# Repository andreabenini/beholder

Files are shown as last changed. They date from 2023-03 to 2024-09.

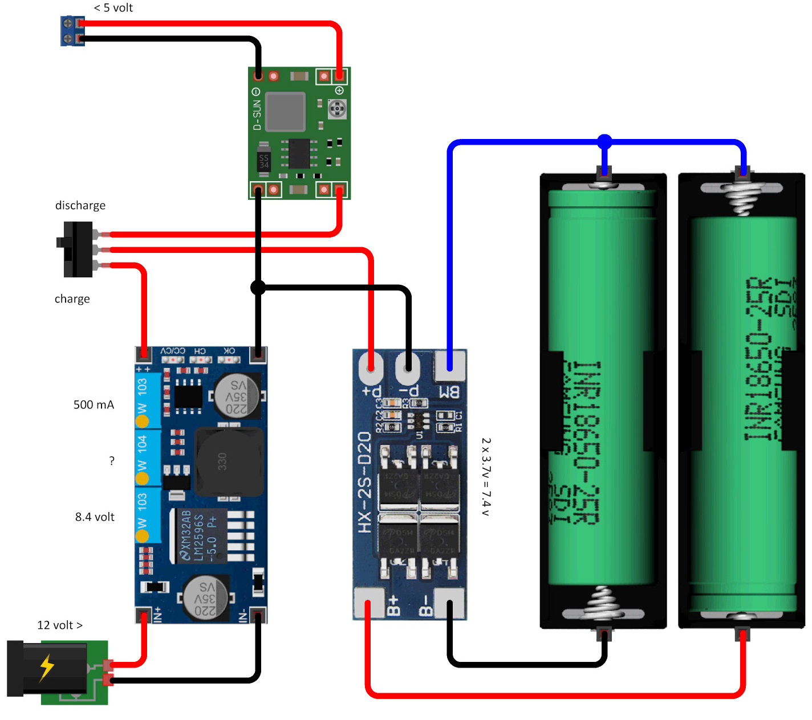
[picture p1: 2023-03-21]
hardware/bms+charger+batteries+PSU.jpg

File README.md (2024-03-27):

# Beholder
Small wheeled home patrol robot. It comes up in two shapes:
- **microguard**. Low profile and tiny bot  
    _Under active development, use it as a reference_
- **rollie**. Two wheeled, ball shaped, self balancing bot  
    _Mechanical assembly completed, on hold. Microguard has 
    now the priority_

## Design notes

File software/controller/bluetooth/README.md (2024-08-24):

| Supported Targets | ESP32 | ESP32-C2 | ESP32-C3 | ESP32-C6 | ESP32-H2 | ESP32-P4 | ESP32-S2 | ESP32-S3 |
| --- | ----- | --- | --- | --- | --- | --- | --- | --- |

# Bluetooth joypad controller sample software

## Folder contents

The project **sample_project** contains one source file in C language [main.c](main/main.c). The file is located in folder [main](main).

ESP-IDF projects are built using CMake. The project build configuration is contained in `CMakeLists.txt`
files that provide set of directives and instructions describing the project's source files and targets
(executable, library, or both). 

Below is short explanation of remaining files in the project folder.

```
├── CMakeLists.txt
├── main
│   ├── CMakeLists.txt
│   └── main.c
└── README.md                  This is the file you are currently reading
```
Additionally, the sample project contains Makefile and component.mk files, used for the legacy Make based build system. 
They are not used or needed when building with CMake and idf.py.

## sdkconfig
- `sdkconfig` file will be automatically generated with `idf.py set-target esp32` command and it's based on architecture feature
    related configuration `sdkconfig.defaults.*` files

## bluetooth
gamepad information
```txt
    BT : a0:5a:5e:11:ac:ff, COD: major: PERIPHERAL, minor: 2, service: 0x001, RSSI: -70, NAME: Wireless Controller
                            RSSI: -70, USAGE: GENERIC, COD: PERIPHERAL[GAMEPAD] srv 0x001, UUID16: 0x0000, NAME: Wireless Controller
```

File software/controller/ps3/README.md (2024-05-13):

# PS3 SixAxis DualShock BT Controller
This amazing electronic device is cheap and precise enough to be used as a primary 
input device for driving the robot when paired with a human.
I have decided to enable builtin bluetooth capabilities in order to support direct
connection with it, this directory contains utilities and documentation for a full
PS3 controller BT support.

## Sixpair utility
Compile and use it in order to attach your controller to the robot, address reported
in the PS3 controller should be the same of the bot firmware, for example:
```sh
./sixpair 1a:2b:3c:01:01:01
```
#### Compile
- This program uses dynamic usb libraries, usually they need to be installed and might
    have these names: `libusb-1_0-devel`, `libusb-compat-devel`.  
- `libusb-compat-devel` provides compatibility level with older linux bt stack somewhat
    mandatory to use it with the program
- Compile with: `gcc sixpair.c -lusb -o sixpair` or use `make.sh` provided utility

## Arduino demo
- Open Arduino IDE
- Menu File/Preferences, field: _"Additional Boards Manager URLs"_, add this board info:
    > https://dl.espressif.com/dl/package_esp32_index.json
- Press **OK** to confirm
- Menu _Tools/Boards/Board Manager_, search _"esp32"_ and select proper board: esp32-c3 or whatever
- Press **Install** button and then close the board manager with the **Close** button
- Menu _Tools/Manage Libraries_, search: _"ps3 controller host"_ and select the
    "Jeffrey van Pernis" library, press **Install** button and **Close** once done
- Open _"arduino_ps3/arduino_ps3.ino"_ sketch with Arduino IDE, verify, compile and upload as usual
    > #### arduino_ps3.ino
    > Arduino based test utility for dealing with ps3 controllers.
    > This sample uses the arduino IDE and provide a working demo for testing
    > controller pairing and basic events from keys and thumbsticks.

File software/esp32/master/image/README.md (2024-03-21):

## Partition table
Getting current partition table from the device
```sh
idf.py partition-table
# *******************************************************************************
## ESP-IDF Partition Table for this project
## Name,     Type,  SubType, Offset,   Size,  Flags
#  nvs,      data,  nvs,     0x9000,   16K,
#  otadata,  data,  ota,     0xd000,   8K,
#  phy_init, data,  phy,     0xf000,   4K,
#  factory,  app,   factory, 0x10000,  200K,
#  ota_0,    app,   ota_0,   0x50000,  1400K,
#  ota_1,    app,   ota_1,   0x1b0000, 1400K,
# *******************************************************************************
```

## Flashing device
```sh
# Default command applied from ESP-IDF Visual Studio Code plugin
/home/ben/.espressif/python_env/idf5.3_py3.11_env/bin/python
    /home/ben/esp/esp-idf/components/esptool_py/esptool/esptool.py
    -p /dev/ttyUSB0 -b 460800 --before default_reset --after hard_reset 
    --chip esp32 write_flash --flash_mode dio --flash_freq 40m
    --flash_size 4MB 
    0x1000 bootloader/bootloader.bin
    0x10000 server.bin
    0x8000 partition_table/partition-table.bin
    0xd000 ota_data_initial.bin

# Flashing a single partition, simplest command ever. Always check partition start address
python $IDF_PATH/components/esptool_py/esptool/esptool.py --chip esp32 --port /dev/ttyUSB0 write_flash 0x110000 ./build/server.bin
```

### Flashing software
```sh
export PORT=/dev/$(dmesg | grep -E 'pl2303.*ttyUSB' | tail -n 1 | awk '{print $NF}'); echo $PORT

# Partition OTA_0 only
python $IDF_PATH/components/esptool_py/esptool/esptool.py --port $PORT --baud 460800 --chip esp32 write_flash --flash_mode dio --flash_freq 40m --flash_size 4MB 0x50000 ./image/partition.ota0.bin

# Completely erase the MCU flash
python $IDF_PATH/components/esptool_py/esptool/esptool.py --port $PORT --baud 460800 --before default_reset --after hard_reset --chip esp32 erase_flash

# Init MCU with all my default values (dir: ~beholder/software/esp32/master)
export PORT=/dev/$(dmesg | grep -E 'pl2303.*ttyUSB' | tail -n 1 | awk '{print $NF}'); echo "Flashing on $PORT port"
python $IDF_PATH/components/esptool_py/esptool/esptool.py   \
    --port $PORT --baud 460800 --chip esp32 write_flash --flash_mode dio --flash_freq 40m --flash_size 4MB   \
    0x1000  ./image/bootloader.bin          \
    0x8000  ./image/partition-table.bin     \
    0xd000  ./image/ota_data_initial.bin    \
    0x10000 ./image/partition.factory.bin   \
    0x50000 ./build/server.bin

```

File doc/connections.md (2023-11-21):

# Peripherals and Connections

| Pro Mini | Type | Pins |
|---|---| ---: |
| Serial | Dedicated RX/TX | 2 |
| Motor 1 | PWM(1), Digital(2) | 3 |
| Motor 2 | PWM(1), Digital(2) | 3 |
| Servo Cam  | PWM(1) | 1 |
| Led | Digital I/O | 1 |
| DHT11 Temp | Analog ADC | 1 |
| Button | Digital | 1 |

| ESP32 | Type | Pins |
|---|---| ---: |
| Camera | Native | **ALL** |
| Serial | Dedicated RX/TX | 2 |

# External Links
- https://www.ebay.com/itm/384893528800

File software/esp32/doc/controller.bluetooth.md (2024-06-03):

# bluepad32 library

## Installation
**NOTE:** Execute all following steps in a IDF enabled shell, 
  see [Install](install.md) notes for it
```sh
# Clone repository
cd
cd esp
git clone https://github.com/bluekitchen/btstack
# git clone --recursive https://github.com/ricardoquesada/bluepad32.git
# # Apply provided patches
# cd bluepad32/external/btstack/
# git apply ../patches/*.patch
# Integrate it to ESP-IDF
cd port/esp32               # ~/esp/bluepad32/external/btstack/port/esp32
# - Double check $IDF_PATH environment variable, it must exists before proceeding
# - scripts always takes care about the ./components path and the entire ESP-IDF env.
#   It can also deal with updates too
./integrate_btstack.py
```

## Examples
- Located in bluepad32/examples/esp32
- `idf.py clean`
- `idf.py set-target esp32c3`
- `idf.py build`
- `idf.py -p /dev/ttyACM0 flash`
- `idf.py -p /dev/ttyACM0 monitor`

Configuration
- `idf.py -p /dev/ttyACM0 monitor`

&nbsp;<br>&nbsp;<br>&nbsp;<br>&nbsp;<br>

# Useful projects and links
- https://github.com/jvpernis/esp32-ps3 (not supporting latest ESP-IDF framework)
- https://github.com/openobjects/PS4-esp32 (a port of the above, somewhat workable but outdated too)
- https://www.google.com/search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
- https://github.com/ricardoquesada/bluepad32 (latest kid in town, based on btstack codebase)
- https://github.com/bluekitchen/btstack
- https://github.com/bluekitchen/btstack/tree/master/port/esp32
- https://bluekitchen-gmbh.com/btstack/#examples/examples/
- https://github.com/ricardoquesada/bluepad32/issues/65#issuecomment-1987046804
- https://github.com/ricardoquesada/bluepad32/issues?page=1&q=is%3Aissue
- https://bluepad32.readthedocs.io/en/stable/supported_gamepads/
- https://github.com/h2zero/esp-nimble-cpp

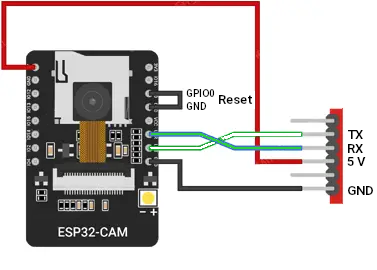
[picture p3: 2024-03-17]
software/esp32/doc/development.png

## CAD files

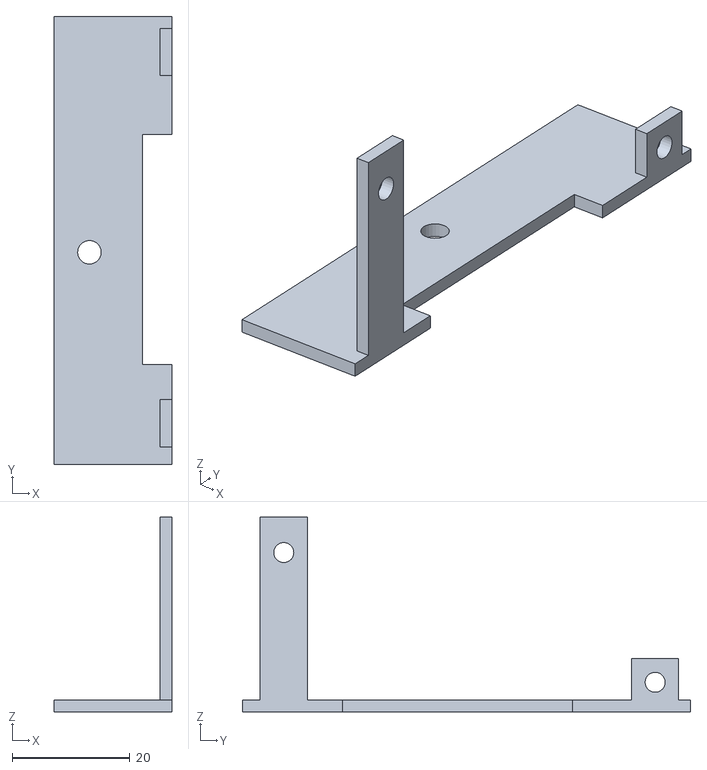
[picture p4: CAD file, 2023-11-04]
hardware/2.0/rollie2-ProMini Holder.stl
20.0 x 76.0 x 33.0

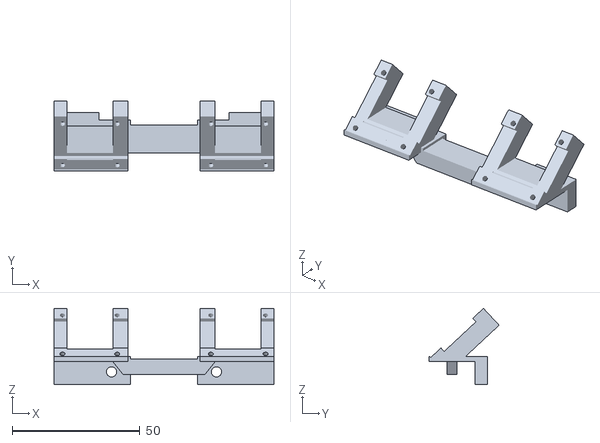
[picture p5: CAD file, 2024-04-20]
hardware/microguard.1.0/microguard-Display Holder.stl
86.0 x 27.5 x 29.8

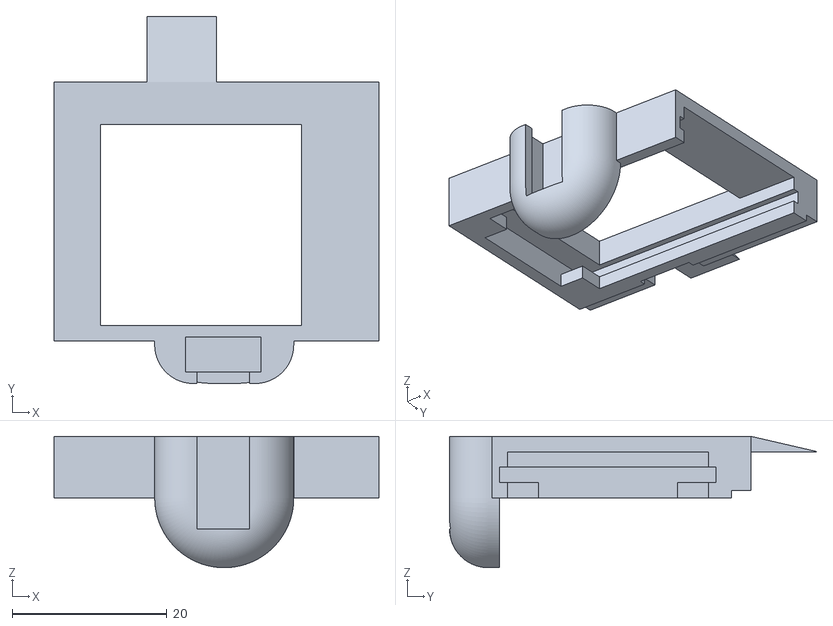
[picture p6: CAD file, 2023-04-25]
hardware/rollie-Camera Holder.stl
42.0 x 47.5 x 17.0

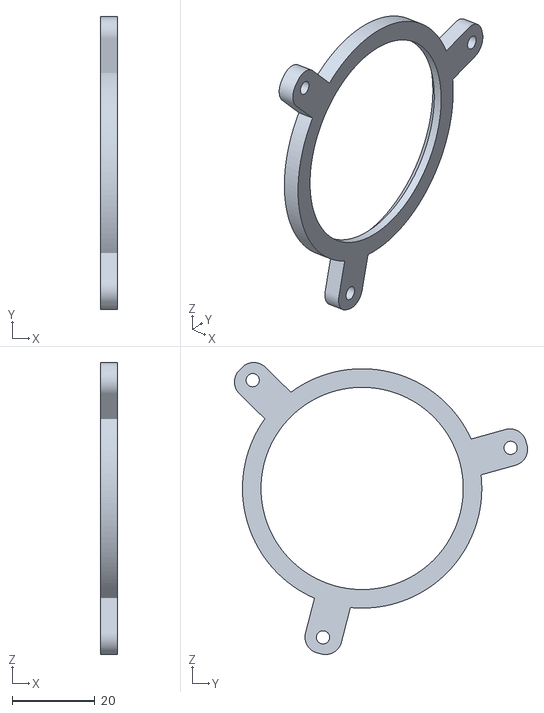
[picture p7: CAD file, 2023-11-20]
hardware/rollie.3.0/rollie3-Right Bearing Outer Cap Front.stl
4.00 x 71.0 x 70.8

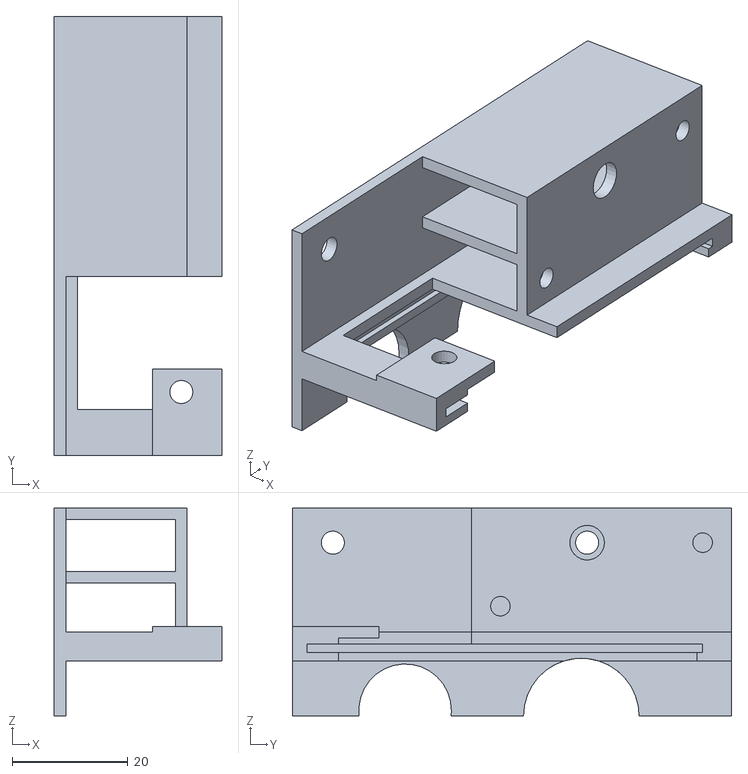
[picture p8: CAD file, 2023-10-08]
hardware/2.0/rollie2-Power Supply Board.stl
29.0 x 76.0 x 36.0

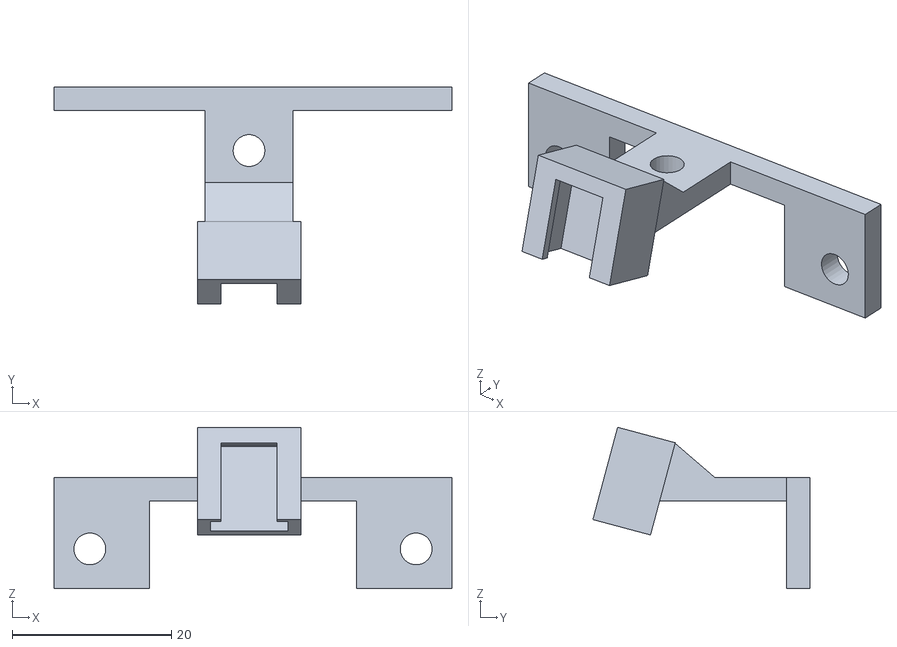
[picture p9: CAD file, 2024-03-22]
hardware/microguard.1.0/microguard-Camera holder.stl
50.0 x 27.3 x 20.3

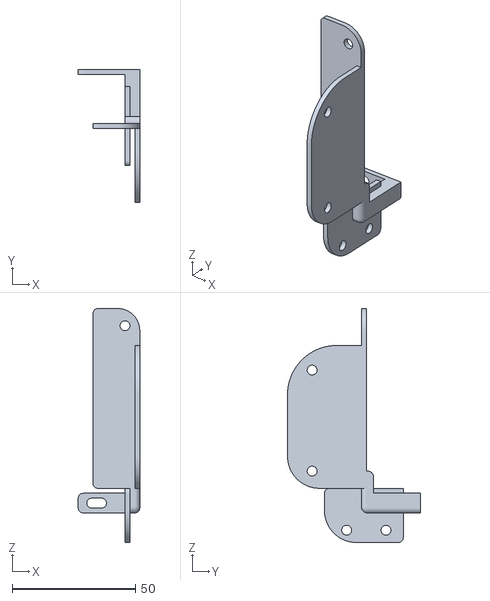
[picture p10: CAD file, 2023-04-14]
hardware/rollie-Arduino Mount.stl
25.0 x 54.0 x 95.0

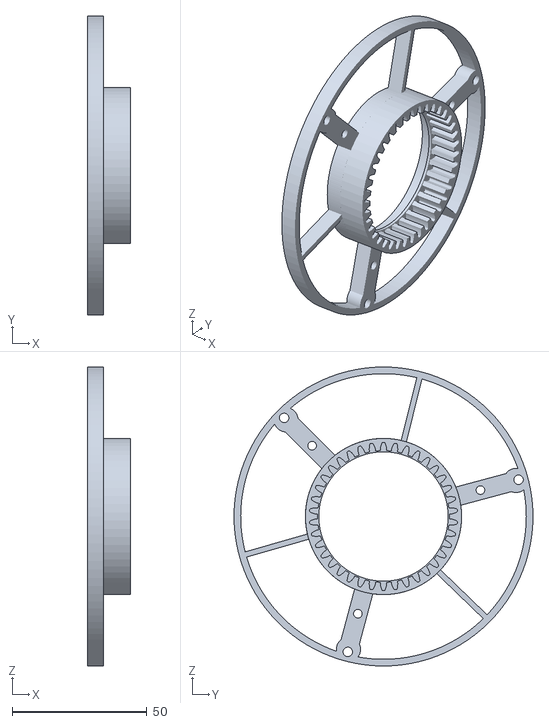
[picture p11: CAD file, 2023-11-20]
hardware/rollie.3.0/rollie3-Left Wheel Rim.stl
16.0 x 111.0 x 111.0

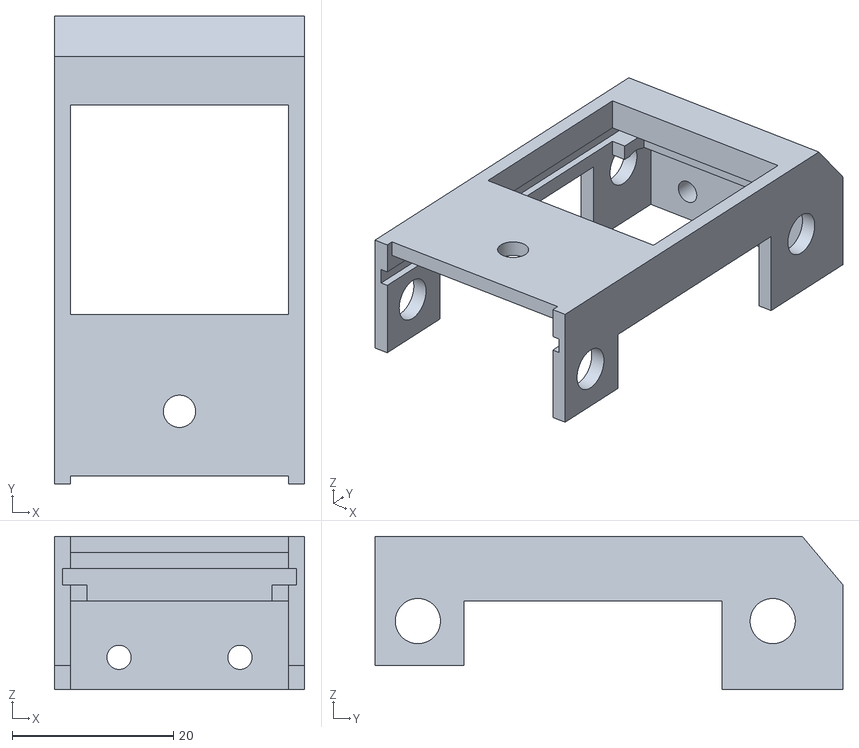
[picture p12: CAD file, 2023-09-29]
hardware/2.0/rollie2-ESP32 Holder.stl
31.0 x 58.0 x 19.0

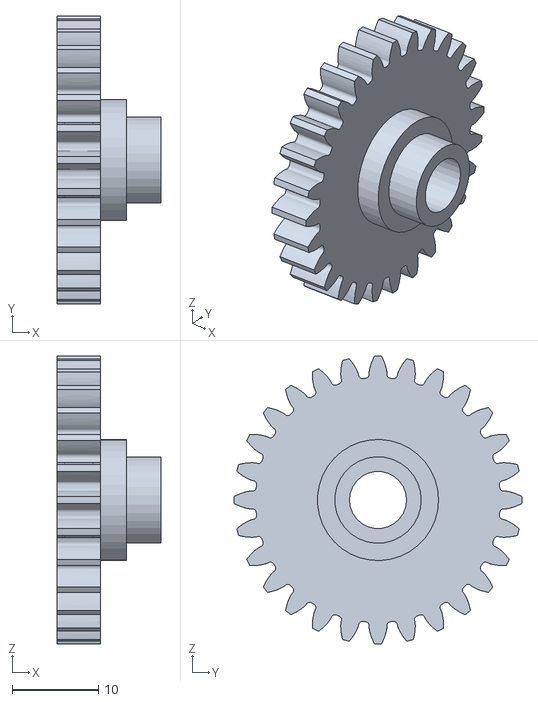
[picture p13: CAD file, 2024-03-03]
hardware/microguard.1.0/microguard-gear left.stl
12.0 x 33.3 x 33.3

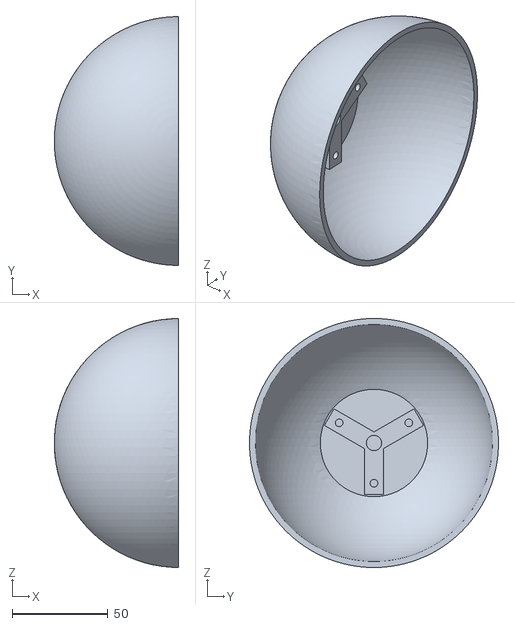
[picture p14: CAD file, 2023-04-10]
hardware/rollie-Wheel Left.stl
65.0 x 130.0 x 130.0

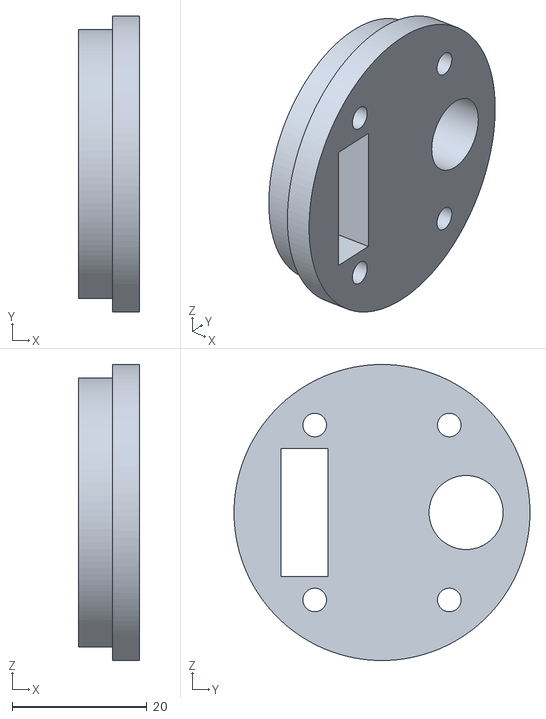
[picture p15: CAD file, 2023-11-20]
hardware/rollie.3.0/rollie3-Right Bearing Inner Front.stl
9.00 x 44.0 x 44.0

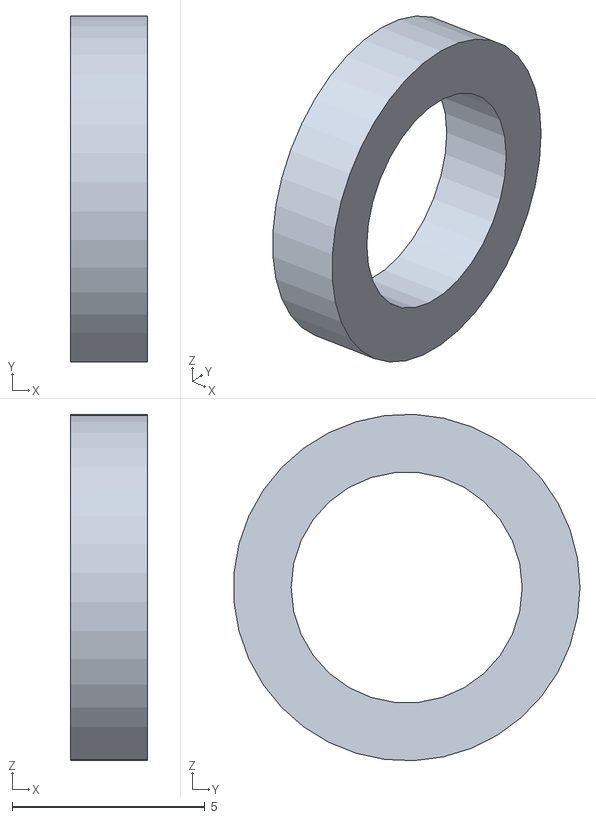
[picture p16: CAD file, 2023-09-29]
hardware/2.0/rollie2-Cylinder Spacer.stl
2.00 x 8.98 x 8.99

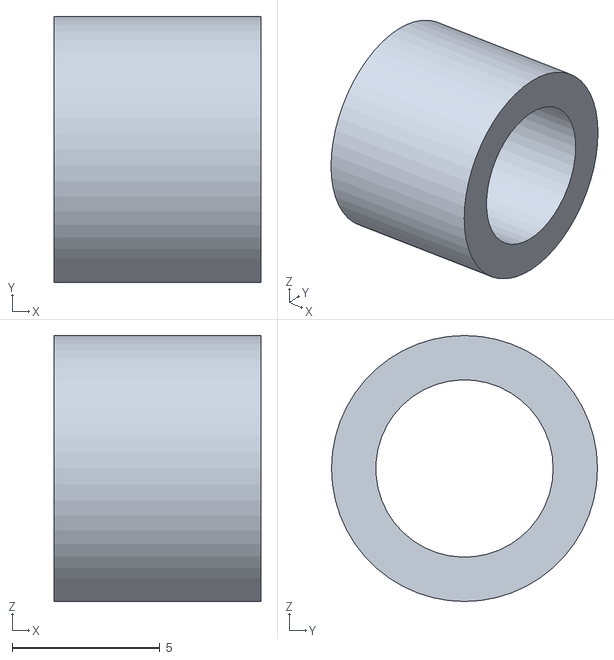
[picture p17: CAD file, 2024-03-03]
hardware/microguard.1.0/microguard-cylinder spacer2.stl
7.00 x 9.00 x 9.00

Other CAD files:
hardware/rollie-Base.stl
hardware/rollie.3.0/rollie3-Right Bearing InnerConnector.stl
hardware/2.0/rollie2-wheel Right Inner Back.stl
hardware/microguard.1.0/microguard-cylinder spacer1.stl
hardware/2.0/rollie2-Battery Holder Right.stl
hardware/2.0/rollie2-Battery Holder.stl
hardware/2.0/rollie2-Shoulder Left.stl
hardware/2.0/rollie2-Shoulder Right.stl
hardware/2.0/rollie2-servo Arm.stl
hardware/2.0/rollie2-wheel Left Cap Front.stl
hardware/2.0/rollie2-wheel Left Gear Pinion.stl
hardware/2.0/rollie2-wheel Left Inner Back.stl
hardware/2.0/rollie2-wheel Left Inner Front.stl
hardware/2.0/rollie2-wheel Left Wheel.stl
hardware/2.0/rollie2-wheel Right Cap Front.stl
hardware/2.0/rollie2-wheel Right Gear Pinion.stl
hardware/2.0/rollie2-wheel Right Inner Front.stl
hardware/2.0/rollie2-wheel Right Wheel.stl
hardware/3.0/rollie3-ESP32 Holder.stl
hardware/3.0/rollie3-Holder Spacer.stl
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

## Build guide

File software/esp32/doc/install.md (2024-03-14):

# Installation
## ESP-IDF
No visual studio code plugins are stricly required, you can use the whole environment from command line:
```sh
# Install ESP-IDF
mkdir $HOME/esp
cd esp
git clone --recursive https://github.com/espressif/esp-idf.git
cd esp-idf

# Install ESP32 Camera libraries
cd components
git clone https://github.com/espressif/esp32-camera
cd ..

# Add user to 'uucp' in /etc/group

# Install ESP-IDF
./install.sh all
```

### **Enter virtual environment**
```sh
# . ./export.sh
. $HOME/esp/esp-idf/export.sh
idf.py --help
# Examples in:  $HOME/esp/esp-idf/examples
```

### **Create and build a sample project**
```sh
cd ~/esp
cp -r $IDF_PATH/examples/get-started/hello_world .
cd hello_world
idf.py build
```

## Visual Studio Plugin: "Espressif IDF"
- Install the visual studio plugin from **Extensions**, it's called "Espressif IDF"
- From _Command Palette_ (Ctrl+Shift+P) select: **"ESP-IDF: Configure ESP-IDF extension"**
- To configure this extension there are two options: Express, Advanced. Select _"Express"_
- From configuration window set these values in fields:
  - Select download server: **Github**
  - Uncheck flag **"Show all ESP-IDF tags"**
  - Select ESP-IDF version: **Find ESP-IDF in your system**
  - Enter ESP-IDF directory (IDF_PATH): **/home/ben/esp/esp-idf**
  - Enter ESP-IDF Tools directory (IDF_TOOLS_PATH): **/home/ben/esp/esp-idf**
  - Select Python version: **/usr/bin/python**
- Close then window when all settings have been configured

# Project Management
## Project Setup
For every project, by default, IntelliSense is present, but the environment may not give
any indication if there is a problem. To fix that:
- Go to `.vscode` > `settings.json` and set the `C_Cpp.intelliSenseEngine` to `default`.  
  Previously it was set to `Tag Parser.`
- Now if there is an error in a C file, a red wavy line appears beneath that code

## New Project
To create a new ESP-IDF project just:
- Select: **"ESP-IDF: New Project"** from _"Command Palette" (Ctrl+Shift+P)_
- From 'New Project' form, first page:
  - Enter the project name
  - Enter the project directory
  - Choose ESP-IDF board, pick _'Custom Board'_ if unsure
  - if _Custom Board_ is selected the additional combo box: "Choose ESP-IDF Target"
    must be set to: "ESP32 module"
  - Select the dedicated serial port if applicable or let it unconfigured if unsure
  - Press "Choose Template" when finished
- From second page:
  - Set the combo box to "ESP-IDF", original value is: "Extension"
  - Select project skeleton: "`/ esp-idf / get-started / sample_project`"
  - Press button "Create project using template sample_project"
- A new project will be created
- Go to `.vscode` > `settings.json` and set the `C_Cpp.intelliSenseEngine` to `default`.  
  Previously it was set to `Tag Parser`. Now if there is an error in a C file, a red wavy
  line appears beneath that code
- Press button "ESP-IDF Build project" _(Ctrl+E, B)_ in the bottom bar to create the initial build

## Partitions information
From the shell in a properly set ESP-IDF terminal you can see current and active partition table
suitable for the device
```sh
idf.py partition-table
```

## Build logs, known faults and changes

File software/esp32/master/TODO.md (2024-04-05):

# Planned features
- Physical button on ATMega to reboot the ESP (or both devices)

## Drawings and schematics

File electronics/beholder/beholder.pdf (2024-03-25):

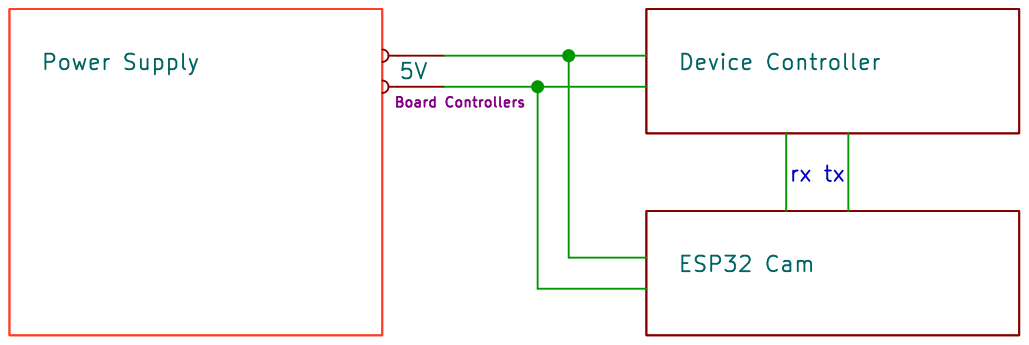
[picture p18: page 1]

File: beholder.kicad_sch Sheet: / Ben

Id: 1/4 Title: beholder Robot Schematics

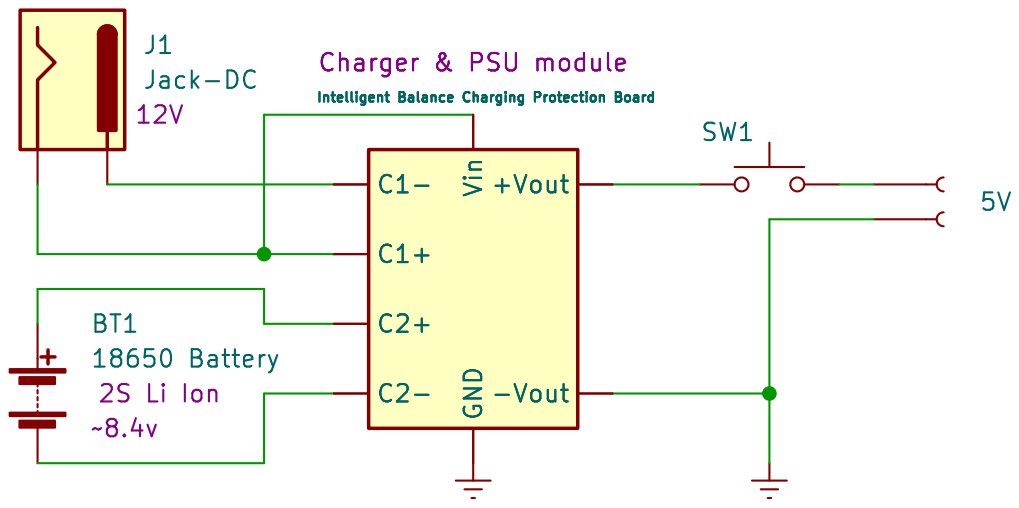
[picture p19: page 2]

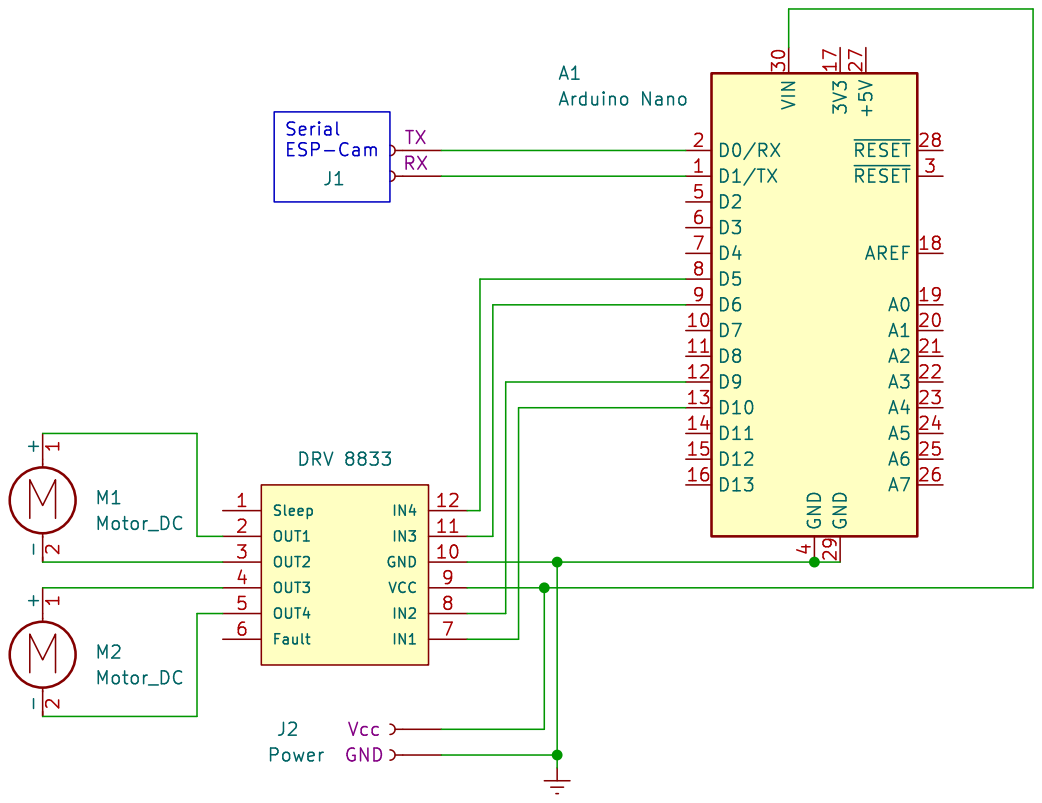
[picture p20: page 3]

TX Serial ESP-Cam

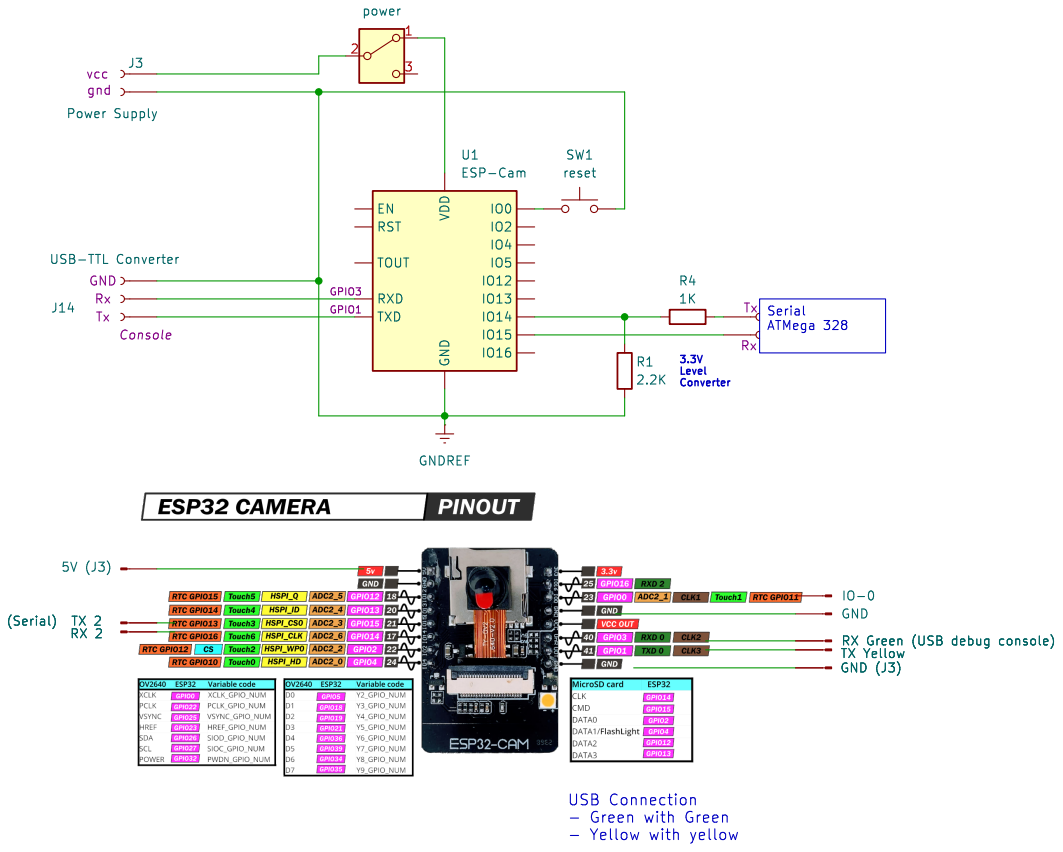
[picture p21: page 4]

IO-0 GND (J3) RX Green (USB debug console) SW1

1K J14 USB-TTL Converter Tx Rx GND

Id: 4/4 Title: File: espcam.kicad_sch Sheet: /ESP32 Cam/ GND

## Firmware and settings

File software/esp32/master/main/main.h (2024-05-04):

#ifndef MAIN__H
#define MAIN__H

#include "esp_task_wdt.h"

/**
 * Set project log level, Default is ESP_LOG_INFO. This define can disable logging all at once (for dealing with other serial devices for example)
 * Log level can also be changed with:
 *      - CONFIG_LOG_MAXIMUM_LEVEL setting in menuconfig
 *      - esp_log_level_set() in esp_log.h
 * Possible log values are:
 *      ESP_LOG_NONE
 *      ESP_LOG_ERROR
 *      ESP_LOG_WARN
 *      ESP_LOG_INFO        (default)
 *      ESP_LOG_DEBUG
 *      ESP_LOG_VERBOSE
 */
// #define LOG_LOCAL_LEVEL ESP_LOG_NONE


// Program configuration variables
#define VAR_LEN                     100

#define VAR_WIFI_SSID               "wifissid"
#define VAR_WIFI_PASSWORD           "wifipassword"
#define VAR_UPDATE_URL              "firmwareurl"
#define VAR_SECURITY_KEY            "secret"
// Bluetooth variables
#define VAR_BT_ADDRESS              "bluetooth"
// Camera variables
#define VAR_CAMERA_RESOLUTION       "cam_resolution"
#define VAR_CAMERA_QUALITY          "cam_quality"

#include "secret.h"
// Inside secret.h there are just these two definitions, feel free to create
// your secret.h file and keep them separated or uncomment those two lines below
// #define WIFI_SSID                   "yourSSID"
// #define WIFI_PASSWORD               "SecretWIFIPassword"
// [Default values] Wireless configuration
#define WIFI_MAX_RETRIES            5
#define WIFI_RETRY_TIMEOUT          1500        // ms
// [Default values] Bluetooth configuration
#define DEFAULT_BT_MAC_ADDRESS      "1a:2b:3c:01:01:01"
// [Default values] Firmware updates
#define DEFAULT_FIRMWARE_URL        "http://192.168.0.16:8000/firmware"
#define DEFAULT_SECURITY_KEY        "42"
// [Default values] camera settings
#define DEFAULT_CAMERA_RESOLUTION   "8"         // (sensor.h) typedef enum framesize_t
#define DEFAULT_CAMERA_QUALITY      "30"


// Camera configuration
// Program configuration
#define TAG_APP                     "Rollie"
// #define BOOTLOADER_ONLY


// User defined functions
// #define PROGRAM_HALT                esp_task_wdt_delete(NULL); while (1){vTaskDelay(portMAX_DELAY);}
#define PROGRAM_HALT                while (1){vTaskDelay(portMAX_DELAY);}

#endif

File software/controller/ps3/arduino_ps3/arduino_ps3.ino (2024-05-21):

#include <Ps3Controller.h>
/*
 *  Configuration Setup
 *      - ESP32-CAM
 *          Board: AI Thinker ESP32-CAM
 *          Library Manager:
 *              - Install: "ps3 controller host"
 */
//#define CONTROLLER_MAC  "1a:2b:3c:01:01:01"       // This will always work (it's not an unicast address)
#define CONTROLLER_MAC  "70:04:1d:93:89:a6"       // Device specific, set yours here

int player = 0;
int battery = 0;

void notify() {
    //--- Digital cross/square/triangle/circle button events ---
    if (Ps3.event.button_down.cross)
        Serial.println("Started pressing the cross button");
    if (Ps3.event.button_up.cross)
        Serial.println("Released the cross button");

    if (Ps3.event.button_down.square)
        Serial.println("Started pressing the square button");
    if (Ps3.event.button_up.square)
        Serial.println("Released the square button");

    if (Ps3.event.button_down.triangle)
        Serial.println("Started pressing the triangle button");
    if (Ps3.event.button_up.triangle)
        Serial.println("Released the triangle button");

    if (Ps3.event.button_down.circle)
        Serial.println("Started pressing the circle button");
    if (Ps3.event.button_up.circle)
        Serial.println("Released the circle button");

    //--------------- Digital D-pad button events --------------
    if (Ps3.event.button_down.up)
        Serial.println("Started pressing the up button");
    if (Ps3.event.button_up.up)
        Serial.println("Released the up button");

    if (Ps3.event.button_down.right)
        Serial.println("Started pressing the right button");
    if (Ps3.event.button_up.right)
        Serial.println("Released the right button");

    if (Ps3.event.button_down.down)
        Serial.println("Started pressing the down button");
    if (Ps3.event.button_up.down)
        Serial.println("Released the down button");

    if (Ps3.event.button_down.left)
        Serial.println("Started pressing the left button");
    if (Ps3.event.button_up.left)
        Serial.println("Released the left button");

    //------------- Digital shoulder button events -------------
    if (Ps3.event.button_down.l1)
        Serial.println("Started pressing the left shoulder button");
    if (Ps3.event.button_up.l1)
        Serial.println("Released the left shoulder button");

    if (Ps3.event.button_down.r1)
        Serial.println("Started pressing the right shoulder button");
    if (Ps3.event.button_up.r1)
        Serial.println("Released the right shoulder button");

    //-------------- Digital trigger button events -------------
    if (Ps3.event.button_down.l2)
        Serial.println("Started pressing the left trigger button");
    if (Ps3.event.button_up.l2)
        Serial.println("Released the left trigger button");

    if (Ps3.event.button_down.r2)
        Serial.println("Started pressing the right trigger button");
    if (Ps3.event.button_up.r2)
        Serial.println("Released the right trigger button");

    //--------------- Digital stick button events --------------
    if (Ps3.event.button_down.l3)
        Serial.println("Started pressing the left stick button");
    if (Ps3.event.button_up.l3)
        Serial.println("Released the left stick button");

    if (Ps3.event.button_down.r3)
        Serial.println("Started pressing the right stick button");
    if (Ps3.event.button_up.r3)
        Serial.println("Released the right stick button");

    //---------- Digital select/start/ps button events ---------
    if (Ps3.event.button_down.select)
        Serial.println("Started pressing the select button");
    if (Ps3.event.button_up.select)
        Serial.println("Released the select button");

    if (Ps3.event.button_down.start)
        Serial.println("Started pressing the start button");
    if (Ps3.event.button_up.start)
        Serial.println("Released the start button");

    if (Ps3.event.button_down.ps)
        Serial.println("Started pressing the Playstation button");
    if (Ps3.event.button_up.ps)
        Serial.println("Released the Playstation button");


    //---------------- Analog stick value events ---------------
   if (abs(Ps3.event.analog_changed.stick.lx) + abs(Ps3.event.analog_changed.stick.ly) > 2) {
       Serial.print("Moved the left stick:");
       Serial.print(" x="); Serial.print(Ps3.data.analog.stick.lx, DEC);
       Serial.print(" y="); Serial.print(Ps3.data.analog.stick.ly, DEC);
       Serial.println();
    }

   if (abs(Ps3.event.analog_changed.stick.rx) + abs(Ps3.event.analog_changed.stick.ry) > 2) {
       Serial.print("Moved the right stick:");
       Serial.print(" x="); Serial.print(Ps3.data.analog.stick.rx, DEC);
       Serial.print(" y="); Serial.print(Ps3.data.analog.stick.ry, DEC);
       Serial.println();
   }

   //--------------- Analog D-pad button events ----------------
   if (abs(Ps3.event.analog_changed.button.up)) {
       Serial.print("Pressing the up button: ");
       Serial.println(Ps3.data.analog.button.up, DEC);
   }

   if (abs(Ps3.event.analog_changed.button.right)) {
       Serial.print("Pressing the right button: ");
       Serial.println(Ps3.data.analog.button.right, DEC);
   }

   if (abs(Ps3.event.analog_changed.button.down)) {
       Serial.print("Pressing the down button: ");
       Serial.println(Ps3.data.analog.button.down, DEC);
   }

   if (abs(Ps3.event.analog_changed.button.left)) {
       Serial.print("Pressing the left button: ");
       Serial.println(Ps3.data.analog.button.left, DEC);
   }

   //---------- Analog shoulder/trigger button events ----------
   if (abs(Ps3.event.analog_changed.button.l1)) {
       Serial.print("Pressing the left shoulder button: ");
       Serial.println(Ps3.data.analog.button.l1, DEC);
   }

   if (abs(Ps3.event.analog_changed.button.r1)) {
       Serial.print("Pressing the right shoulder button: ");
       Serial.println(Ps3.data.analog.button.r1, DEC);
   }

   if (abs(Ps3.event.analog_changed.button.l2)) {
       Serial.print("Pressing the left trigger button: ");
       Serial.println(Ps3.data.analog.button.l2, DEC);
   }

   if (abs(Ps3.event.analog_changed.button.r2)) {
       Serial.print("Pressing the right trigger button: ");
       Serial.println(Ps3.data.analog.button.r2, DEC);
   }

   //---- Analog cross/square/triangle/circle button events ----
   if (abs(Ps3.event.analog_changed.button.triangle)) {
       Serial.print("Pressing the triangle button: ");
       Serial.println(Ps3.data.analog.button.triangle, DEC);
   }

   if (abs(Ps3.event.analog_changed.button.circle)) {
       Serial.print("Pressing the circle button: ");
       Serial.println(Ps3.data.analog.button.circle, DEC);
   }

   if (abs(Ps3.event.analog_changed.button.cross)) {
       Serial.print("Pressing the cross button: ");
       Serial.println(Ps3.data.analog.button.cross, DEC);
   }

   if (abs(Ps3.event.analog_changed.button.square)) {
       Serial.print("Pressing the square button: ");
       Serial.println(Ps3.data.analog.button.square, DEC);
   }

   //---------------------- Battery events ---------------------
    if (battery != Ps3.data.status.battery) {
        battery = Ps3.data.status.battery;
        Serial.print("The controller battery is ");
        if (battery == ps3_status_battery_charging)         Serial.println("charging");
        else if (battery == ps3_status_battery_full)        Serial.println("FULL");
        else if (battery == ps3_status_battery_high)        Serial.println("HIGH");
        else if (battery == ps3_status_battery_low)         Serial.println("LOW");
        else if (battery == ps3_status_battery_dying)       Serial.println("DYING");
        else if (battery == ps3_status_battery_shutdown)    Serial.println("SHUTDOWN");
        else Serial.println("UNDEFINED");
    }
} /**/

void onConnect() {
    Serial.println("Connected.");
} /**/

void setup() {
    Serial.begin(115200);
    Serial.println("setup() Begin");
    Ps3.attach(notify);
    Ps3.attachOnConnect(onConnect);
    Ps3.begin(CONTROLLER_MAC);             // Device specific, set yours here
    Serial.println("setup() Ready");
} /**/

void loop() {
    if (!Ps3.isConnected()) {
        return;
    }
    //-------------------- Player LEDs -------------------
    Serial.print("Setting LEDs to player "); Serial.println(player, DEC);
    Ps3.setPlayer(player);
    player += 1;
    if (player > 10) player = 0;

    //------ Digital cross/square/triangle/circle buttons ------
    if (Ps3.data.button.cross && Ps3.data.button.down )
        Serial.println("Pressing both the down and cross buttons");
    if (Ps3.data.button.square && Ps3.data.button.left )
        Serial.println("Pressing both the square and left buttons");
    if (Ps3.data.button.triangle && Ps3.data.button.up )
        Serial.println("Pressing both the triangle and up buttons");
    if (Ps3.data.button.circle && Ps3.data.button.right )
        Serial.println("Pressing both the circle and right buttons");

    if (Ps3.data.button.l1 && Ps3.data.button.r1 )
        Serial.println("Pressing both the left and right bumper buttons");
    if (Ps3.data.button.l2 && Ps3.data.button.r2 )
        Serial.println("Pressing both the left and right trigger buttons");
    if (Ps3.data.button.l3 && Ps3.data.button.r3 )
        Serial.println("Pressing both the left and right stick buttons");
    if (Ps3.data.button.select && Ps3.data.button.start )
        Serial.println("Pressing both the select and start buttons");

    delay(2000);
} /**/

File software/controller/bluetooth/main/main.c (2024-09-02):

/*
 * SPDX-FileCopyrightText: 2021-2024 Espressif Systems (Shanghai) CO LTD
 *
 * SPDX-License-Identifier: Unlicense OR CC0-1.0
 */
#include <stdio.h>
#include <stdlib.h>
#include <string.h>

#include "freertos/FreeRTOS.h"
#include "freertos/task.h"
#include "freertos/event_groups.h"
#include "esp_system.h"
#include "esp_wifi.h"
#include "esp_event.h"
#include "esp_log.h"
#include "nvs_flash.h"
#include "esp_bt.h"

#if CONFIG_BT_NIMBLE_ENABLED
#include "host/ble_hs.h"
#include "nimble/nimble_port.h"
#include "nimble/nimble_port_freertos.h"
#else
#include "esp_bt_defs.h"
#include "esp_gap_ble_api.h"
#include "esp_gatts_api.h"
#include "esp_gatt_defs.h"
#include "esp_bt_main.h"
#include "esp_bt_device.h"
#endif

#if CONFIG_BT_NIMBLE_ENABLED
#include "host/ble_hs.h"
#include "nimble/nimble_port.h"
#include "nimble/nimble_port_freertos.h"
#define ESP_BD_ADDR_STR         "%02x:%02x:%02x:%02x:%02x:%02x"
#define ESP_BD_ADDR_HEX(addr)   addr[0], addr[1], addr[2], addr[3], addr[4], addr[5]
#else
#include "esp_bt_defs.h"
#include "esp_gap_ble_api.h"
#include "esp_gatts_api.h"
#include "esp_gatt_defs.h"
#include "esp_bt_main.h"
#include "esp_bt_device.h"
#endif

#include "esp_hidh.h"
#include "esp_hid_gap.h"


#include "main.h"


#if CONFIG_BT_HID_HOST_ENABLED
static const char * remote_device_name = CONFIG_EXAMPLE_PEER_DEVICE_NAME;
#endif // CONFIG_BT_HID_HOST_ENABLED

char *bda2str(esp_bd_addr_t bda, char *str, size_t size) {
    if (bda == NULL || str == NULL || size < 18) {
        return NULL;
    }
    uint8_t *p = bda;
    sprintf(str, "%02x:%02x:%02x:%02x:%02x:%02x", p[0], p[1], p[2], p[3], p[4], p[5]);
    return str;
} /**/


uint8_t bdacmp(uint8_t *src, esp_bd_addr_t dest) {
    for (uint8_t i=0; i<6; i++) {
        if (src[i] != dest[i]) {
            return 1;
        }
    }
    return 0;
} /**/


void hidh_callback(void *handler_args, esp_event_base_t base, int32_t id, void *event_data) {
    esp_hidh_event_t event = (esp_hidh_event_t)id;
    esp_hidh_event_data_t *param = (esp_hidh_event_data_t *)event_data;
    switch (event) {
    case ESP_HIDH_OPEN_EVENT: {
        if (param->open.status == ESP_OK) {
            const uint8_t *bda = esp_hidh_dev_bda_get(param->open.dev);
            ESP_LOGI(TAG_APP, ESP_BD_ADDR_STR " OPEN: %s", ESP_BD_ADDR_HEX(bda), esp_hidh_dev_name_get(param->open.dev));
            esp_hidh_dev_dump(param->open.dev, stdout);
        } else {
            ESP_LOGE(TAG_APP, " OPEN failed!");
        }
        break;
    }
    case ESP_HIDH_BATTERY_EVENT: {
        const uint8_t *bda = esp_hidh_dev_bda_get(param->battery.dev);
        ESP_LOGI(TAG_APP, ESP_BD_ADDR_STR " BATTERY: %d%%", ESP_BD_ADDR_HEX(bda), param->battery.level);
        break;
    }
    case ESP_HIDH_INPUT_EVENT: {
        const uint8_t *bda = esp_hidh_dev_bda_get(param->input.dev);
        ESP_LOGI(TAG_APP, " INPUT: %8s, MAP: %2u, ID: %3u, Len: %d", 
                            esp_hid_usage_str(param->input.usage), param->input.map_index, param->input.report_id, param->input.length);
        ESP_LOG_BUFFER_HEX(TAG_APP, param->input.data, param->input.length);
        break;
    }
    case ESP_HIDH_FEATURE_EVENT: {
        const uint8_t *bda = esp_hidh_dev_bda_get(param->feature.dev);
        ESP_LOGI(TAG_APP, ESP_BD_ADDR_STR " FEATURE: %8s, MAP: %2u, ID: %3u, Len: %d", ESP_BD_ADDR_HEX(bda),
                 esp_hid_usage_str(param->feature.usage), param->feature.map_index, param->feature.report_id,
                 param->feature.length);
        ESP_LOG_BUFFER_HEX(TAG_APP, param->feature.data, param->feature.length);
        break;
    }
    case ESP_HIDH_CLOSE_EVENT: {
        const uint8_t *bda = esp_hidh_dev_bda_get(param->close.dev);
        ESP_LOGI(TAG_APP, ESP_BD_ADDR_STR " CLOSE: %s", ESP_BD_ADDR_HEX(bda), esp_hidh_dev_name_get(param->close.dev));
        break;
    }
    default:
        ESP_LOGI(TAG_APP, "hidh_callback()  default event [%d]", event);
        break;
    }
} /**/


void hidDetectionTask(void *pvParameters) {
    size_t results_len = 0;
    esp_hid_scan_result_t *results;
    while (results_len == 0) {      // Keep it here until a peripheral is detected
        results = NULL;
        ESP_LOGI(TAG_APP, "hidDetectionTask() Scanning begin... (duration %ds)", SCAN_DURATION_SECONDS);
        //start scan for HID devices
        esp_hid_scan(SCAN_DURATION_SECONDS, &results_len, &results);
        ESP_LOGI(TAG_APP, "hidDetectionTask() Scanning end, found %u results", results_len);
    }
    ESP_LOGI(TAG_APP, "hidDetectionTask() Found [%u] results", results_len);
    esp_hid_scan_result_t *r = results;
    esp_hid_scan_result_t *cr = NULL;
    while (r) {
        printf("  -> %s " ESP_BD_ADDR_STR ", RSSI: %d, USAGE: %s, ", 
                (r->transport == ESP_HID_TRANSPORT_BLE) ? "BLE" : "BT ", ESP_BD_ADDR_HEX(r->bda), r->rssi, esp_hid_usage_str(r->usage));
#if CONFIG_BT_BLE_ENABLED
        if (r->transport == ESP_HID_TRANSPORT_BLE) {
            cr = r;
            printf("APPEARANCE: 0x%04x, ", r->ble.appearance);
            printf("ADDR_TYPE: '%s', ", ble_addr_type_str(r->ble.addr_type));
        }
#endif /* CONFIG_BT_BLE_ENABLED */
#if CONFIG_BT_NIMBLE_ENABLED
        if (r->transport == ESP_HID_TRANSPORT_BLE) {
            cr = r;
            printf("APPEARANCE: 0x%04x, ", r->ble.appearance);
            printf("ADDR_TYPE: '%d', ", r->ble.addr_type);
        }
#endif /* CONFIG_BT_BLE_ENABLED */
#if CONFIG_BT_HID_HOST_ENABLED
        if (r->transport == ESP_HID_TRANSPORT_BT) {
            cr = r;
            printf("COD: %s[", esp_hid_cod_major_str(r->bt.cod.major));
            esp_hid_cod_minor_print(r->bt.cod.minor, stdout);
            printf("] srv 0x%03x, ", r->bt.cod.service);
            print_uuid(&r->bt.uuid);
            printf(", ");
            if (strncmp(r->name, remote_device_name, strlen(remote_device_name)) == 0) {
                break;
            }
        }
#endif /* CONFIG_BT_HID_HOST_ENABLED */
        printf("NAME: %s\n", r->name ? r->name : "");
        r = r->next;
    }

#if CONFIG_BT_HID_HOST_ENABLED
    // BT Demo: Device: Wireless Controller, Remote:HID Mouse Example
    // TODO: Detect device and pair+connect it
    // esp_bd_addr_t controller = BT_CONTROLLER;
    // ESP_LOGW(TAG_APP, "%d", bdacmp((esp_bd_addr_t) BT_CONTROLLER, cr->bda));
    // ESP_LOGW(TAG_APP, "%d", bdacmp(controller, cr->bda));

    ESP_LOGI(TAG_APP, "Device: %s, Remote:%s", cr->name, remote_device_name);
    // if (cr && strncmp(cr->name, remote_device_name, strlen(remote_device_name)) == 0) {
    if (cr && !bdacmp((esp_bd_addr_t) BT_CONTROLLER, cr->bda)) {
        ESP_LOGI(TAG_APP, "esp_hidh_dev_open()");
        esp_hidh_dev_open(cr->bda, cr->transport, cr->ble.addr_type);
    } else {
        ESP_LOGE(TAG_APP, "Device " ESP_BD_ADDR_STR " unknown", ESP_BD_ADDR_HEX(cr->bda));
    }
#else
    if (cr) {
        //open the last result
        esp_hidh_dev_open(cr->bda, cr->transport, cr->ble.addr_type);
    }
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

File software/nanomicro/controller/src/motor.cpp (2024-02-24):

#include "motor.h"


/**
 * motorInit - Init motor control circuit
 */
void motorInit() {
    // Motor control inputs to OUTPUT
    pinMode(MOTOR1_IN_1, OUTPUT);
    pinMode(MOTOR1_IN_2, OUTPUT);
    pinMode(MOTOR2_IN_3, OUTPUT);
    pinMode(MOTOR2_IN_4, OUTPUT);
    // Turn off motors - Initial state
    digitalWrite(MOTOR1_IN_1, LOW);
    digitalWrite(MOTOR1_IN_2, LOW);
    digitalWrite(MOTOR2_IN_3, LOW);
    digitalWrite(MOTOR2_IN_4, LOW);
} /**/


void motorPWM(int8_t dutyCycle, uint8_t pin1, uint8_t pin2) {
    char buffer[200];

    uint8_t pwm = round(abs(2.55 * dutyCycle));
    if (dutyCycle < 0) {        // Backward
        digitalWrite(pin1, LOW);
        analogWrite(pin2, pwm);
        sprintf(buffer, "\npin1[%d]:LOW, pin2[%d]:%d", pin1, pin2, pwm);
    } else {                    // Stop or forward
        digitalWrite(pin2, LOW);
        analogWrite(pin1, pwm);
        sprintf(buffer, "\npin1[%d]:%d, pin2[%d]:LOW", pin1, pwm, pin2);
    }
    Serial.println(buffer);
} /**/


/**
 * motor - Control motor movements
 * @param motorNumber (uint8_t) 0: all motors, 1: motor1, 2: motor2
 * @param dutyCycle   (int8_t)  Duty cycle percentage.  0..100: forward, -100..0: backward
 */
void motor(uint8_t motorNumber, int8_t dutyCycle) {
    switch (motorNumber) {
    case 0:
        motorPWM(dutyCycle, MOTOR1_IN_1, MOTOR1_IN_2);
        motorPWM(dutyCycle, MOTOR2_IN_3, MOTOR2_IN_4);
        break;
    case 1:
        motorPWM(dutyCycle, MOTOR1_IN_1, MOTOR1_IN_2);
        break;
    case 2:
        motorPWM(dutyCycle, MOTOR2_IN_3, MOTOR2_IN_4);
        break;
    }
    // DEBUG from here
    char buffer[200];
    sprintf(buffer, "Motor:%d, duty:%d.", motorNumber, dutyCycle);
    Serial.println(buffer);
} /**/

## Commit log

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2023-02-08 DC Motor flanges to the wheels
    [rollie-Flange Left.stl]
2023-02-11 Camera base arm with pwm servo
    [rollie-Camera Holder.stl]
2023-02-12 integrated camera support arm
    [rollie-Camera Support.stl]
2023-02-12 Arduino mount for Rollie
    [rollie-Arduino Mount.stl]
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2023-03-01 Battery wedges and boards holder
    [rollie-Battery Wedge + BMS.stl, rollie-Battery Wedge.stl]
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2023-03-03 Updated border, more space for inserting zip ties
    [rollie-Battery Wedge + BMS.stl, rollie-Battery Wedge.stl]
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2023-03-06 TowerPro micro servo 9g holder
    [rollie-Holder Servo.stl]
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2023-03-14 Rounded circle to avoid internal wheel contact
    [rollie-Arduino Mount.stl]
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2023-03-19 Adding ext power probe
    [rollie.kicad_sch]
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2023-03-25 Adding motors, L298N, Probe
    [rollie.kicad_sch]
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2023-03-26 Arduino mount bracked with space for 3DoF sensor
    [rollie-Arduino Mount.stl]
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2023-03-29 Adding GY-521 3 Axis IMU
    [rollie.kicad_sch]
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2023-04-14 Adding arduino mounting bracket to bot
    [rollie-Arduino Mount.stl]
2023-04-25 Adding ESP32 Cam holder
    [rollie-Camera Holder.stl]
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2023-05-11 New battery holder, left side
    [rollie2-Battery Holder.stl]
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2023-05-14 Left wheel, servo motor cap, inner wheel
    [rollie2-wheel Left Inner Front.stl]
2023-05-15 Internal left shoulder inside the wheel
    [rollie2-Shoulder Left.stl]
2023-05-16 Left battery holder and electronics outer shell
    [rollie2-Battery Holder.stl]
2023-05-20 Rollie inner wheel, back cap
    [rollie2-wheel Left Inner Back.stl]
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2023-06-06 inner front wheel, right
    [rollie2-wheel Right Inner Front.stl]
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2023-06-10 Left front cap, thin and tied to the ball bearing
    [rollie2-wheel Left Cap Front.stl]
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2023-06-14 Inner back cylinder for the left wheel
    [rollie2-wheel Left Inner Back.stl]
2023-06-15 New arm for the servo, to avoid M3 nut
    [rollie2-servo Arm.stl]
2023-06-15 Cylinder spacer front rod under ESP32-CAM
    [rollie2-Cylinder Spacer.stl]
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2023-06-18 Added more space between gears and motor bracket
    [rollie2-wheel Left Inner Back.stl]
2023-06-18 Right wheel, front cap
    [rollie2-wheel Right Cap Front.stl]
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2023-07-03 New right wheel part
    [rollie2-wheel Right Wheel.stl]
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2023-09-22 Right wheel battery holder
    [rollie2-Battery Holder Right.stl]
2023-09-24 Power supply boards holder
    [rollie2-Power Supply Board.stl]
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2023-09-27 Inner wheel spacers Spacers between ball bearings and motor mount brackets
    [rollie2-wheel Left Inner Back.stl, rollie2-wheel Right Inner Back.stl]
2023-09-27 Inner back right wheel fix
    - Fixing spacer position to fit current layout
    [rollie2-wheel Right Inner Back.stl]
2023-09-29 Removing L298N H-Bridge controller
    Now using cheap and more reliable DRV8833
    [rollie2-L298 Base1.stl, rollie2-L298 Base2.stl, rollie2-L298 Base3.stl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]
2023-09-29 Cylinder spacers between ESP32 holder
    [rollie2-Cylinder Spacer.stl]
2023-09-29 New ESP32 board holder
    Mounted directly on inner rods
    [rollie2-ESP32 Holder.stl]
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2023-10-07 New power supply board
    - Using two UBECs instead of a Step-Down DC converter
    - One ubec for controller boards
    - One ubec for motors and servo
    - Simplified mounting holes installation
    [rollie2-Power Supply Board.stl]
2023-10-08 Adding two UBEC and more optimizations
    - Two UBECs instead of just one DC-DC stepDown converter
    - Shrinking base height
    - removing one screw hole, it's no longer necessary
    [rollie2-Power Supply Board.stl]
2023-11-04 ATmega Pro Mini board holder on right wing
    [rollie2-ProMini Holder.stl]
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2023-11-04 Removing v1.0 of the hardware project
    [microservoArmA3.stl, microservoSG90.stl, rollie-Arduino Mount.stl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]
2023-11-10 Hardware revision 3.0, initial schematics
    [rollie3-ESP32 Holder.stl, rollie3-Holder Spacer.stl, rollie3-Left Bearing Inner Back.stl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]
2023-11-11 New inter connector
    - Adding space for nuts and bolts
    - Bigger surface on top of battery PSU
    [rollie3-Left Bearing InnerConnector.stl]
2023-11-12 Left wheel inner bearing clamp
    [rollie3-Left Bearing Inner Back.stl, rollie3-Left Bearing Inner Front.stl]
2023-11-13 wheel pinion gear, 8 teeth and custom design
    [rollie3-Left Pinion Gear.stl]
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2024-01-25 Upper floor controller deck
    - ATMega controller deck
    - ESP32 controller deck
    [microguard-Controller Deck.stl, microguard-gear left motor.stl]
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2024-02-16 single shoulder for wheels
    - New unified shoulder for both wheels
    - esp-cam mounting sled
    - new baseplate adjusted for the single shoulder
    [microguard-Controller Deck.stl, microguard-shoulder left bearing.stl, microguard-shoulder middle.stl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]
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2024-02-25 New controller deck, slightly adapted to the shape
    [microguard-Controller Deck.stl]
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2024-03-01 Updated mobo deck and wheel caster holder
    - Improved deck for placing components vertically
    - New caster wheel holder shaped on 2.5 mm screws
    [microguard-Controller Deck.stl, microguard-caster wheel holder.stl]
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2024-03-03 Gear Spacers
    Use them near the gearbox as spacers
    [microguard-cylinder spacer1.stl, microguard-cylinder spacer2.stl]
2024-03-03 new gear with an included spacer in it
    [microguard-gear left.stl]
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2024-03-19 New camera holder, now shaped for cable management
    New camera holder better handles the camera cable without
    stretching or compressing it.
    [microguard-Camera holder.stl]
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2024-09-02 Trying to solve error: E (xxx) BT_BTM: BTM_GetSecurityFlags false
    [main.c]
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
